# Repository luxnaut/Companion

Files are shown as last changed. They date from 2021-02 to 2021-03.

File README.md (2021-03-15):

# Companion No. 2
V.2

Companion No. 2 | OSC Comm. Device 
Created by luxnaut 
 
Companion No. 2 is the second iteration in the series of custom controllers designed to send detailed 9-DOF, color, light, and simple gesture data via OSC communication.  

***Note that Arduino has been known to have issues with USB-C adapters when uploading***

***Note that the ESPRESSIF hardware has been having issues on macOS Big Sur, additional help can be found here (https://github.com/espressif/arduino-esp32/issues/4408)***

Required hardware: 
-	Adafruit HUZZAH32 | https://www.adafruit.com/product/3405
-	Adafruit BNO055 (STEMMA QT or standard) | https://www.adafruit.com/product/4754
-	Adafruit APDS9960 | https://www.adafruit.com/product/3595
-	PermaProto Board OR Breadboard | https://www.adafruit.com/product/1609 or https://www.adafruit.com/product/64
-	Lithium Ion Battery OR LiPoly Battery | https://www.adafruit.com/product/354 or https://www.adafruit.com/product/258
-	Soldering Iron and Solder 
-	Solid Strand Wire 

**BEFORE SOLDERING TO PERMA BOARD** it is best practice to lay out the wiring you will be using to make sure everything fits comfortably. 

## Hardware

1	Unless purchased with headers, solder the male headers to your microcontroller and sensors. On the sensors, you need only to solder the	 Vin side of headers. 

2	Make sure to orient the board so that the USB port is close to the edge of the permaboard. Solder the HUZZAH to the board, making sure to leave two spaces available on the side with SDA and SCL and one on the side with 3V and GND.  

3	Wire and solder the positive and negative busses with 3V and GND 

4	Clip the headers on the other side to create a flush surface with the board. 

5	Solder the wires in place for the Vin, GND, SDA, and SCL connections of the first sensor on the “top” part of the perma board. It is perhaps easiest to solder them to the edge closest to the busses. 

6	Place and solder the sensor accordingly, test your connections, snip the headers, and then repeat for the second sensor. 
______

## Software

1	Install the USB driver (https://www.silabs.com/products/development-tools/software/usb-to-uart-bridge-vcp-drivers) for your current OS 

2	Download the CNMAT OSC Arduino Library (https://github.com/CNMAT/OSC) by clicking “code”, then “download zip”. Go into the Arduino IDE, go to “sketch”, “include 
library”, and then “add zip library”. 

3	In the Arduino IDE, go to “Arduino”, “preferences”, and under “Additional Board Manager URLs” paste: 
 	 	 	 	 	 
https://raw.githubusercontent.com/espressif/arduino-esp32/gh-pages/package_esp32_index.json 
 
Then go to “Tools”, “Board”, and then “Boards Manager”. Search for “ESP32” and install 

4	Go to “Tools”, “Manage Libraries”, and install the Adafruit “BNO055” sensor library and the Adafruit “APDS9960” sensor library. This may trigger a popup menu to download the Adafruit Unified Sensor Library; if so, click yes. If not, download it from here (https://github.com/adafruit/Adafruit_Sensor). 
______

## Working with the Companion

1	Connect to your chosen WiFi network. 

***Note that enterprise networks, or networks with restricted access may cause connection errors.***

2	In Arduino, enter the SSID, password, and IP address. Enter a port number for the outPort variable.	 

3	Double check your code settings (board, upload speed, and port are primarily at fault if there’s any upload problems) 

4	Open the serial monitor to confirm everything is uploaded correctly. 

5	Begin OSC communication in your preferred application with your chosen port number and IP on the current network. 

***License***

<br /><span xmlns:dct="http://purl.org/dc/terms/" property="dct:title">Companion No. 2</span> by <a xmlns:cc="http://creativecommons.org/ns#" href="https://github.com/luxnaut/Companion" property="cc:attributionName" rel="cc:attributionURL">luxnaut</a> is licensed under a <a rel="license" href="http://creativecommons.org/licenses/by-nd/4.0/">Creative Commons Attribution-NoDerivatives 4.0 International License</a>.

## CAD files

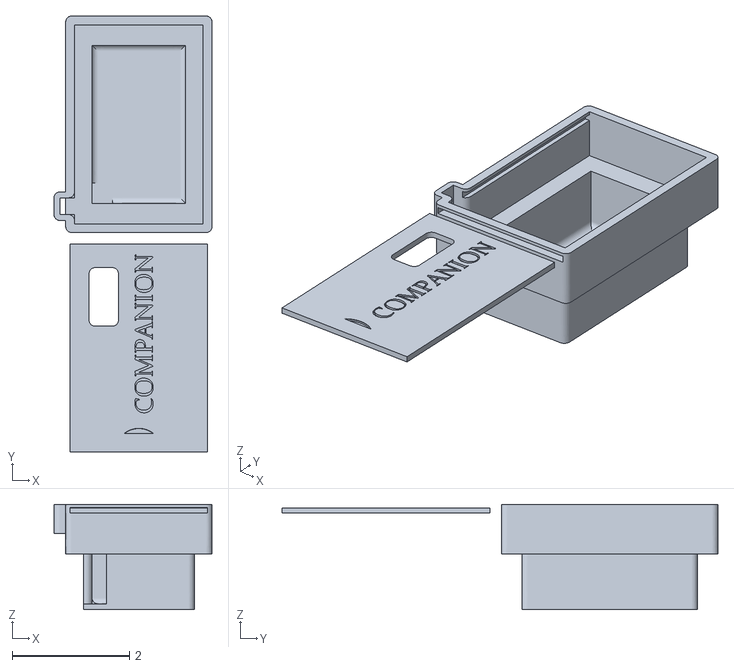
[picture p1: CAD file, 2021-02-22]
3D Models/Companion V.2 Case.stl
2.70 x 7.45 x 1.80

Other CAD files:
3D Models/Companion V.2 Case.obj

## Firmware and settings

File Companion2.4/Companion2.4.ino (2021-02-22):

/* Companion v.2.4
Created by luxnaut */

//Libraries
#include "Adafruit_APDS9960.h" //Color and gesture library
#include <Wire.h> //I2C library
#include <Adafruit_Sensor.h> //Adafruit Unified Sensor System library
#include <Adafruit_BNO055.h> //BNO055 library
#include <utility/imumaths.h> //IMU maths library
#include <WiFi.h> //Wifi library
#include <OSCMessage.h> //OSC message library

//Wifi setup
char ssid[] = "ssid"; //SSID
char pass[] = "pass"; //Password
const IPAddress outIP(127, 0, 0, 1); //Receiving IP address

//UDP 
WiFiUDP UDP; //Instance of UDP for messages

//OSC
const int outPort = 8000; //Port for sending message to receiving IP

//Sensor instances
Adafruit_APDS9960 apds; //Instance of the color/gesture sensor
Adafruit_BNO055 bno = Adafruit_BNO055(55); //Instance of BNO0ff sensor (0x28 or 0x29 I2C address)

//BNO055 sensor variables
float quatW, quatX, quatY, quatZ;
float eulerX, eulerY, eulerZ;
float linAccX, linAccY, linAccZ;
float accelX, accelY, accelZ;
float gyroX, gyroY, gyroZ;
float gravX, gravY, gravZ;
float magnetX, magnetY, magnetZ;

//Light color
uint16_t r, g, b, c;
float red, green, blue, clearL;

void setup() {
  Serial.begin(115200); //Begin serial communication (for testing)
  
  if(!apds.begin()){ //If sensor not found
    Serial.println("Failed to initialize color/gesture sensor");
  } else {
    Serial.println("Color/gesture sensor found!"); //If sensor found
  }

  if(!bno.begin()){ //If sensor not found
    Serial.println("Failed to find abs ori sensor");
  } else {
    Serial.println("Abs ori sensor found!"); //If sensor found
  }

  delay(2500);

  //Enable color/gesture sensors
  apds.enableColor(true); //Enables color sensing
  apds.enableProximity(true); //Enable proximity sensor
  apds.enableGesture(true); //Enable gesture sensor

  //Enable external crystal
  bno.setExtCrystalUse(true); //Enable external crystal use (increased accuracy)

  WiFi.begin(ssid, pass);
}

void loop() {
  imu::Quaternion quat = bno.getQuat();  //W,X,Y,Z Quaternions
  imu::Vector <3> euler = bno.getVector(Adafruit_BNO055::VECTOR_EULER); //X/Y/Z Euler Angles (degrees)
  imu::Vector <3> linAcc = bno.getVector(Adafruit_BNO055::VECTOR_LINEARACCEL); //X/Y/Z Linear Acceleration (m/s^2)
  imu::Vector <3> accel = bno.getVector(Adafruit_BNO055::VECTOR_ACCELEROMETER);//X/Y/Z Acceleration (m/s^2)
  imu::Vector <3> gyro = bno.getVector(Adafruit_BNO055::VECTOR_GYROSCOPE); //X/Y/Z Radian Orientation (rad/s)
  imu::Vector <3> grav = bno.getVector(Adafruit_BNO055::VECTOR_GRAVITY); //X/Y/Z Gravity (m/s^2)
  imu::Vector <3> magnet = bno.getVector(Adafruit_BNO055::VECTOR_MAGNETOMETER); //X/Y/Z Magnetometer (uT)

  apds.getColorData(&r, &g, &b, &c); //Red, green, blue, and clear light

  //Data type conversion to float for OSC communication
  float quatW = (float) quat.w();
  float quatX = (float) quat.x();
  float quatY = (float) quat.y();
  float quatZ = (float) quat.z();

  float eulerX = (float) euler.x();
  float eulerY = (float) euler.y();
  float eulerZ = (float) euler.z();

  float linAccX = (float) linAcc.x();
  float linAccY = (float) linAcc.y();
  float linAccZ = (float) linAcc.z();

  float accX = (float) accel.x();
  float accY = (float) accel.y();
  float accZ = (float) accel.z();

  float gyroX = (float) gyro.x();
  float gyroY = (float) gyro.y();
  float gyroZ = (float) gyro.z();

  float gravX = (float) grav.x();
  float gravY = (float) grav.y();
  float gravZ = (float) grav.z();

  float magX = (float) magnet.x();
  float magY = (float) magnet.y();
  float magZ = (float) magnet.z();

  red = r; 
  green = g;
  blue = b;
  clearL = c;

  //OSC message setup
  OSCMessage msg("/Companion"); //Message tag
  msg.add(quatW).add(quatX).add(quatY).add(quatZ);
  msg.add(eulerX).add(quatY).add(quatZ);
  msg.add(linAccX).add(linAccY).add(linAccZ);
  msg.add(accX).add(accY).add(accZ);
  msg.add(gyroX).add(gyroY).add(gyroZ);
  msg.add(gravX).add(gravY).add(gravZ);
  msg.add(magX).add(magY).add(magZ);
  msg.add(red).add(green).add(blue).add(clearL);
  UDP.beginPacket(outIP, outPort); //UDP setup w/ outIP (address to send to) and outPort (port to send over)
  msg.send(UDP); //Send the message
  UDP.endPacket(); //Close the packet
  msg.empty(); //Empty the message for new data

  delay(10); //Sample rate delay for data smoothing
}
